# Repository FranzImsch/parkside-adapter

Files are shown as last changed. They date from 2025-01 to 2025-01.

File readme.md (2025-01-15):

## Overview

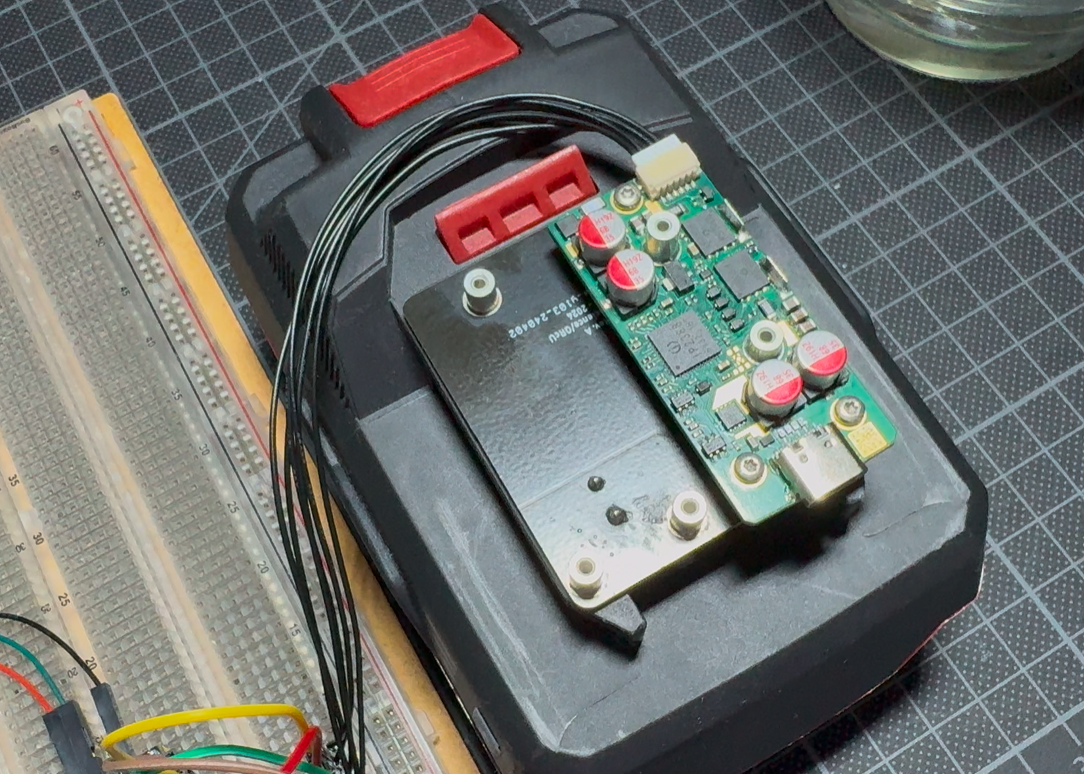
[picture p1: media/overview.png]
Overview image of test setup


Lidl sells batteries for their Parkside-branded power tools. These are 5S lithium-ion batteries that are well-constructed and cost approximately €20 for the 4 Ah version. While the cells are not from premium brands, they appear to be of relatively high quality. For instance, the 4 Ah battery I purchased contains Sunpower INR19/66 cells. Detailed information about these cells can be found here:  
[Parkside INR18650E 2000mAh (Blue) Review](https://lygte-info.dk/review/batteries2012/Parkside%20INR18650E%202000mAh%20(Blue)%20UK.html)  
[Sunpower High-Rate Lithium-Ion Battery Specifications](https://www.sunpowernewenergy.com/product/18650-high-rate-lithium-ion-battery-20p/)

Currently, Lidl offers a USB charger add-on for these batteries, but it has significant limitations. Its output power is restricted to 15 W, and it does not support charging the battery via USB.  
[Product page](https://www.lidl.de/p/parkside-20-v-akku-ladeadapter-pwca-20-li-a1/p100363956)

The adaptor described here comprises a 3D-printed enclosure and a PCB with soldered contacts that connect to the battery terminals. The interface PCB includes two mounting locations for power modules.

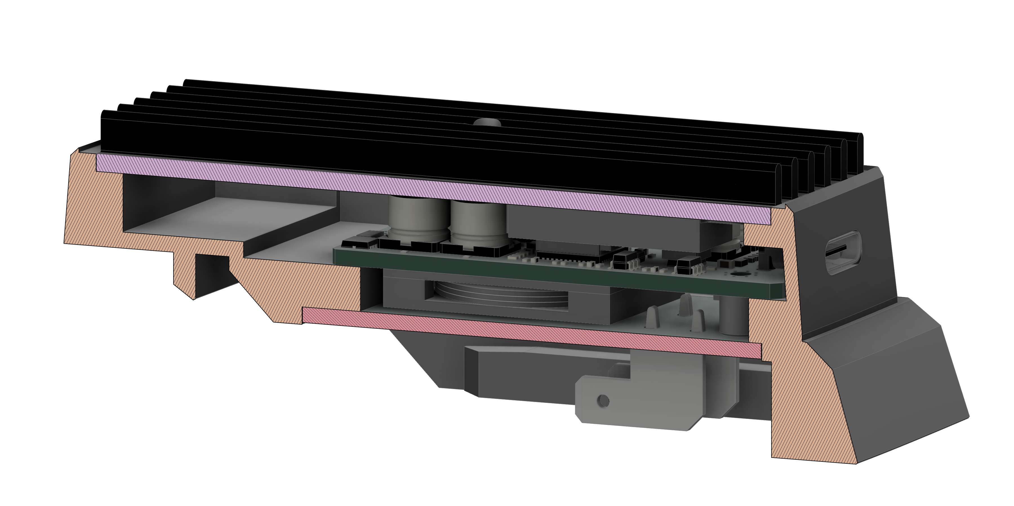
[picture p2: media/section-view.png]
Screenshot of cross section view of CAD model

The screenshot shows a cross section view of the assembly.

The bi-directional 100 W USB-C module, based on the IP2368 chip, is used in the current implementation.

Future developments are planned, including a 240 W power module and a PCB with a microcontroller and control logic.

## IP2368

The IP2368 chip is available in several firmware versions. I chose the IP2368_I2C_NACT variant, which supports I2C communication and can function as a USB-C source immediately upon connection to a battery, without requiring an initial connection to a charger. Sourcing this chip outside China is challenging; I obtained mine via [LCSC](https://www.lcsc.com/product-detail/Power-Management-Specialized_INJOINIC-IP2368_I2C_COUT_C5372184.html). Note that a quotation request is necessary, as this chip is typically not in stock.

## Tasks

- [ ] Create and expand documentation (better photos)
- [ ] Replace the overview photo  
- [ ] Design a PCB for the microcontroller  
- [ ] Test the 100 W power module

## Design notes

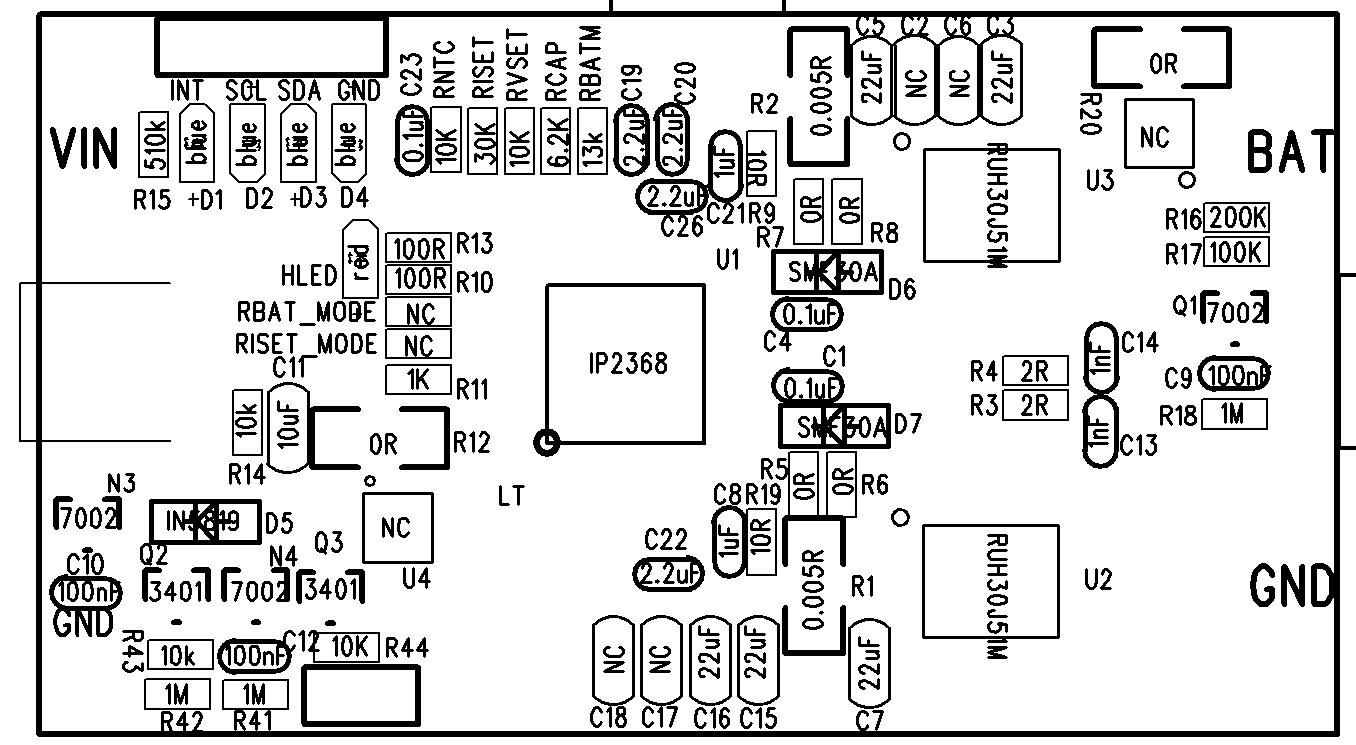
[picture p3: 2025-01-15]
IP2368-datasheets/IP2368_DEMO_V1.4.5/正面贴片图.png

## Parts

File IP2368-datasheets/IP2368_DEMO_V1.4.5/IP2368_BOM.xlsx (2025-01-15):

 | IP2368
物料名称 | 物料型号 | 位号 | 用量 | 备注
贴片电容 | 0805 10uF 25V 10% X5R | C11 | 1
贴片电容 | 0805 22uF 25V 10% X5R | C3, C5, C7, C15, C16 | 5
贴片电容 | 0603 1uF 50V 10% X5R | C8, C21 | 2
贴片电容 | 0603 100nF 50V 10% X5R | C1, C4, C9, C10, C12, C23 | 6
贴片电容 | 0603 1nF 50V 10% X5R | C13, C14 | 2
贴片电容 | 0603 2.2uF 25V 10% X5R | C19, C20, C22, C24, C25, C26 | 6
二极管 | 肖特基二极管,IN5819/S4,SOD-123 | D5 | 1
MOS管 | NMOS,2N7002,SOT23-3 | N3, N4, Q1 | 3
MOS管 | PMOS,FH3401,SOT23-3 | Q2, Q3 | 2
贴片电阻 | 0603 0R 1/10W ＋/-1% | R5, R6, R7, R8 | 4
贴片电阻 | 0603 2R 1/10W ＋/-1% | R3, R4 | 2
贴片电阻 | 0603 10R 1/10W ＋/-1% | R9, R19 | 2
贴片电阻 | 0603 100R 1/10W ＋/-1% | R10, R13 | 2
贴片电阻 | 0603 1K 1/10W ＋/-1% | R11 | 1
贴片电阻 | 0603 6.2K 1/10W ＋/-1% | RCAP | 1
贴片电阻 | 0603 10K 1/10W ＋/-1% | R14, R43, R44, RNTC, RVSET | 5
贴片电阻 | 0603 13K 1/10W ＋/-1% | RBATM | 1
贴片电阻 | 0603 30K 1/10W ＋/-1% | RISET | 1
贴片电阻 | 0603 100K 1/10W ＋/-1% | R17 | 1
贴片电阻 | 0603 200K 1/10W ＋/-1% | R16 | 1
贴片电阻 | 0603 510K 1/10W ＋/-1% | R15 | 1
贴片电阻 | 0603 1M 1/10W ＋/-1% | R18, R41, R42 | 3
贴片电阻 | 1206 0R 1W ＋/-1% | R12, R20 | 2
贴片LED | 0603 蓝色 | D1, D2, D3, D4 | 4
贴片LED | 0603 红色 | HLED | 1
IC | HT7550-2 SOT-89 | U6 | 1
TYPE-C座 | TYPE-C贴板16P,不锈钢,磷铜足1迈,高温黑胶 | USB1 | 1
插件固态电容 | 插件固态电容,100uF/35V,6.3x8 | CP1, CP2 | 2
磁环电感 | 卧式电感,10uH，T050125，直径16mm | L1 | 1
TVS管 | SMF30A,SOD-123 | D6, D7 | 2
合金电阻 | 1206 0.005R 1W ＋/-1% | R1, R2 | 2
IC | RUH30J51M PDFN5060 | U2, U3 | 2
IC | IP2368_NF | U1 | 1

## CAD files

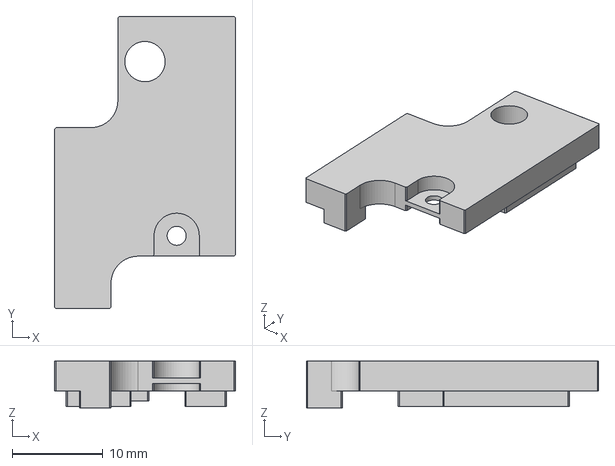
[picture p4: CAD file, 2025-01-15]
100W-Bick-KiCad/Parkside-Heatsink-Adaptor_v2.step
20.0 x 32.3 x 5.19 mm

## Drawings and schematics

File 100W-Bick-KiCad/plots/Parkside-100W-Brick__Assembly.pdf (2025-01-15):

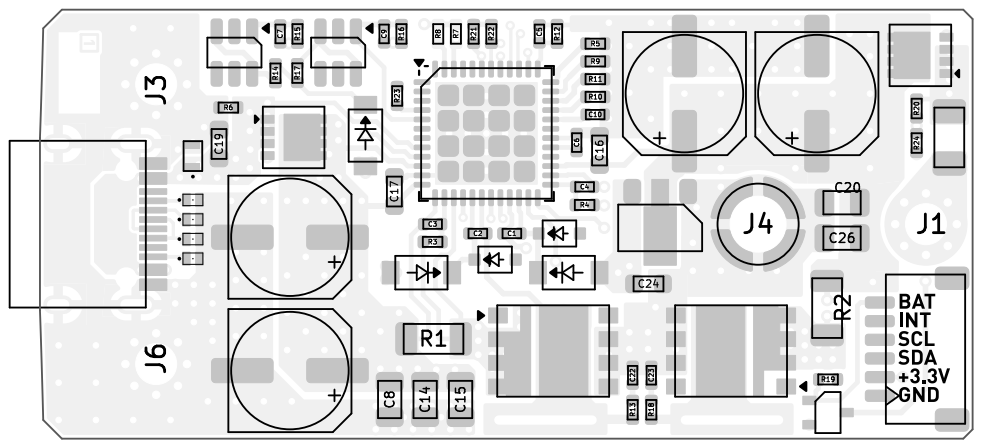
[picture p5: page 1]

Id: 1/1 Title: File: Parkside-100W-Brick.kicad_pcb Sheet: C¹⁶ R1

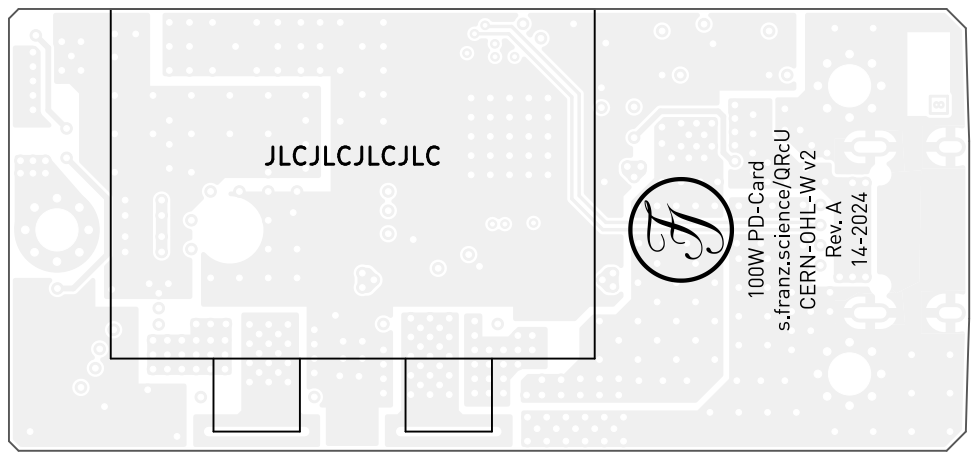
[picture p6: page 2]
D Date: KiCad; E.D.A. 8.0.0 Size: A4; Rev:

8 100WPD-Card s.franz.science/QRcU CERN-OHL-Wv2 Rev.A 14-2024 JLCJLCJLCJLC

Id: 1/1 Title: File: Parkside-100W-Brick.kicad_pcb Sheet:

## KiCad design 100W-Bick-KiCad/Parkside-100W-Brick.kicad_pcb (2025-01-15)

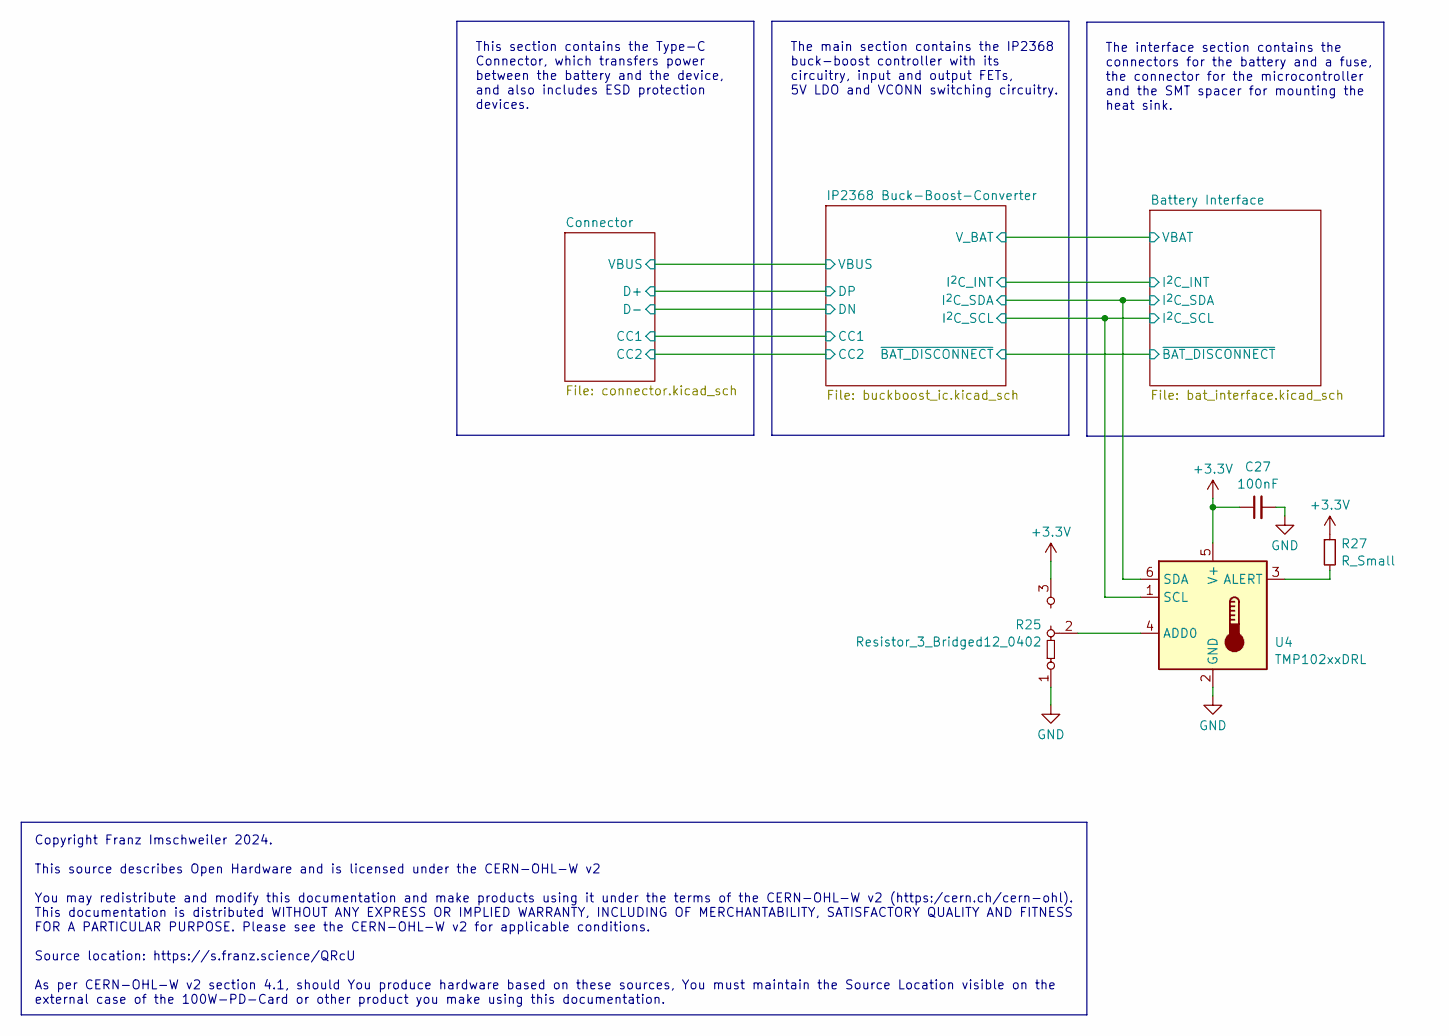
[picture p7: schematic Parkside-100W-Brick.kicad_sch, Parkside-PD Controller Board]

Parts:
C27: 100nF; C_0402_1005Metric_NoSilk
R25: Resistor_3_Bridged12_0402; R_0402_JUMPER3_NoSilk
R27: R_Small; R_0402_1005Metric_NoSilk
U4: TMP102xxDRL; SOT-563_NoSilk

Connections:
+3.3V: C27.1, R25.3 (B), R27.1, U4.5 (V+); also elsewhere on the board
/Battery Interface/I^{2}C_SCL: U4.1 (SCL); also elsewhere on the board
/Battery Interface/I^{2}C_SDA: U4.6 (SDA); also elsewhere on the board
GND: C27.2, R25.1 (A), U4.2 (GND); also elsewhere on the board
unnamed: R25.2 (C), U4.4 (ADD0)
unnamed: R27.2, U4.3 (ALERT)

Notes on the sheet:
The interface section contains the connectors for the battery and a fuse, the connector for the microcontroller and the SMT spacer for mounting the heat sink.
Copyright Franz Imschweiler 2024. This source describes Open Hardware and is licensed under the CERN-OHL-W v2 You may redistribute and modify this documentation and make products using it under the terms of the CERN-OHL-W v2 (https:/cern.ch/cern-ohl). This documentation is distributed WITHOUT ANY E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
This section contains the Type-C Connector, which transfers power between the battery and the device, and also includes ESD protection devices.
The main section contains the IP2368 buck-boost controller with its circuitry, input and output FETs, 5V LDO and VCONN switching circuitry.

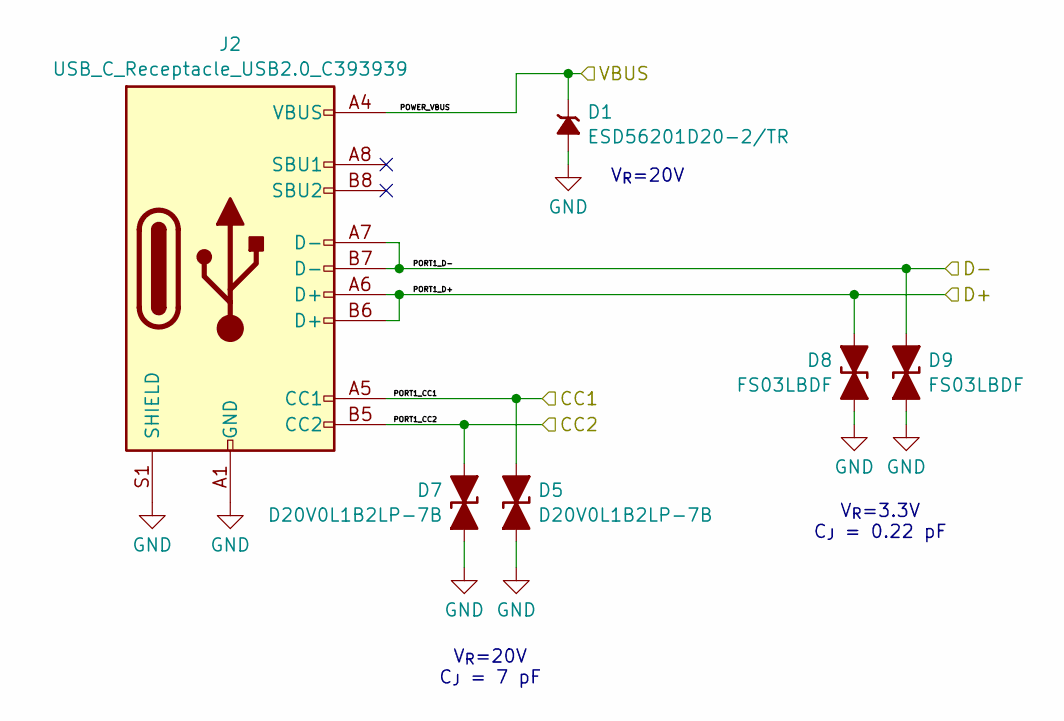
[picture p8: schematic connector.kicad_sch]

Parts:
D1: ESD56201D20-2/TR; ST_QFN1610_1_NoSilk
D5, D7: D20V0L1B2LP-7B; X1-DFN1006-2_P6X1_DIO
D8, D9: FS03LBDF; X1-DFN1006-2_P6X1_DIO
J2: USB_C_Receptacle_USB2.0_C393939; USB_C_Receptacle_C313131_TYPE-C-31-M-12

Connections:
/Connector/PORT1_CC1: D5.1 (A1), J2.A5 (CC1); also elsewhere on the board
/Connector/PORT1_CC2: D7.1 (A1), J2.B5 (CC2); also elsewhere on the board
/Connector/PORT1_D+: D8.1 (A1), J2.A6 (D+), J2.B6 (D+); also elsewhere on the board
/Connector/PORT1_D-: D9.1 (A1), J2.A7 (D-), J2.B7 (D-); also elsewhere on the board
/Connector/POWER_VBUS: D1.1 (K), J2.A4 (VBUS), J2.A9 (VBUS), J2.B4 (VBUS), J2.B9 (VBUS); also elsewhere on the board
GND: D1.2 (A), D5.2 (A2), D7.2 (A2), D8.2 (A2), D9.2 (A2), J2.A1 (GND), J2.A12 (GND), J2.B1 (GND), J2.B12 (GND), J2.S1 (SHIELD); also elsewhere on the board

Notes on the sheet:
V_{R}=20V C_{J} = 7 pF
V_{R}=20V
V_{R}=3.3V C_{J} = 0.22 pF

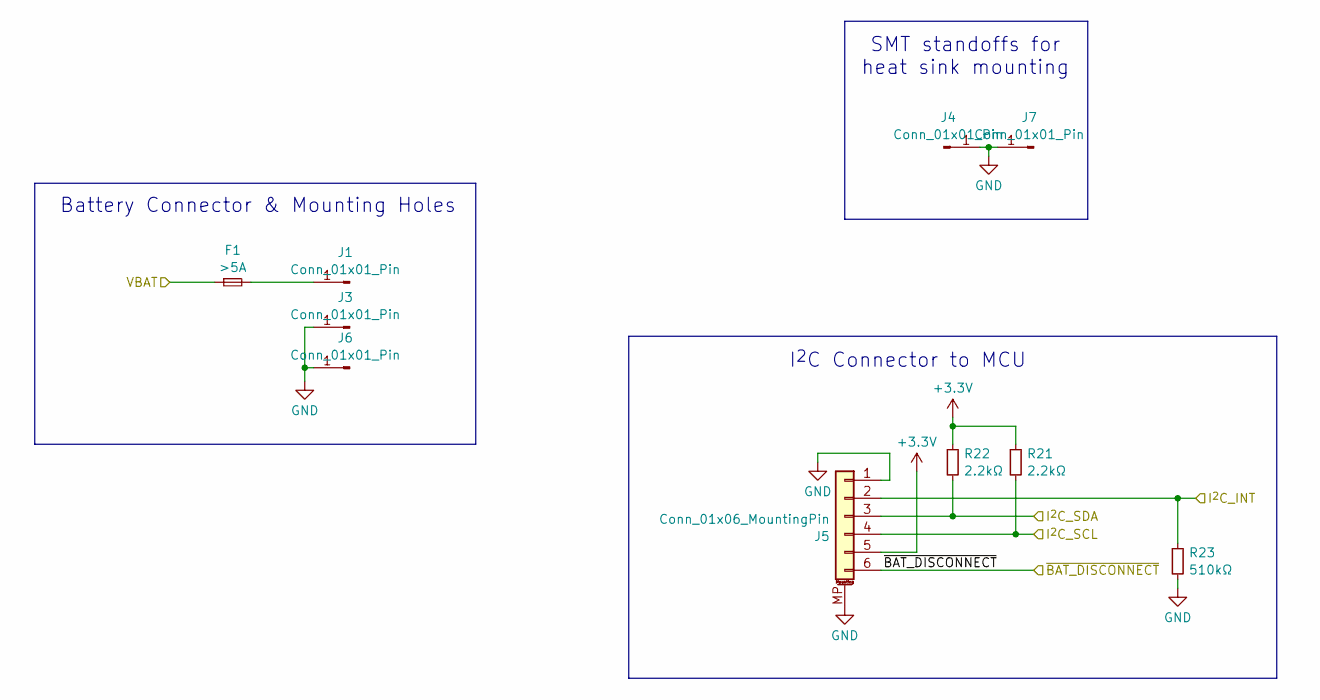
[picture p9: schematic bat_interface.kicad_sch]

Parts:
F1: >5A; Fuse_1206_3216Metric_NoSilk
J1, J3, J6: Conn_01x01_Pin; MountingHole_2.2mm_M2_Pad_Via_NoSilk
J4, J7: Conn_01x01_Pin; Mounting_Wuerth_WA-SMSI-M2_H6mm_9774060243
J5: Conn_01x06_MountingPin; JST_SH_SM06B-SRSS-TB_1x06-1MP_P1.00mm_Horizontal_NoSilk
R21, R22: 2.2kΩ; R_0402_1005Metric_NoSilk
R23: 510kΩ; R_0402_1005Metric_NoSilk

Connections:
+3.3V: J5.5, R21.1, R22.1; also elsewhere on the board
/Battery Interface/I^{2}C_INT: J5.2, R23.1; also elsewhere on the board
/Battery Interface/I^{2}C_SCL: J5.4, R21.2; also elsewhere on the board
/Battery Interface/I^{2}C_SDA: J5.3, R22.2; also elsewhere on the board
/Battery Interface/VBAT: F1.1; also elsewhere on the board
/Battery Interface/~BAT_DISCONNECT: J5.6; also elsewhere on the board
GND: J3.1, J4.1, J5.1, J5.MP (MountPin), J6.1, J7.1, R23.2; also elsewhere on the board
unnamed: F1.2, J1.1

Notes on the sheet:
Battery Connector & Mounting Holes
SMT standoffs for heat sink mounting
I^{2}C Connector to MCU

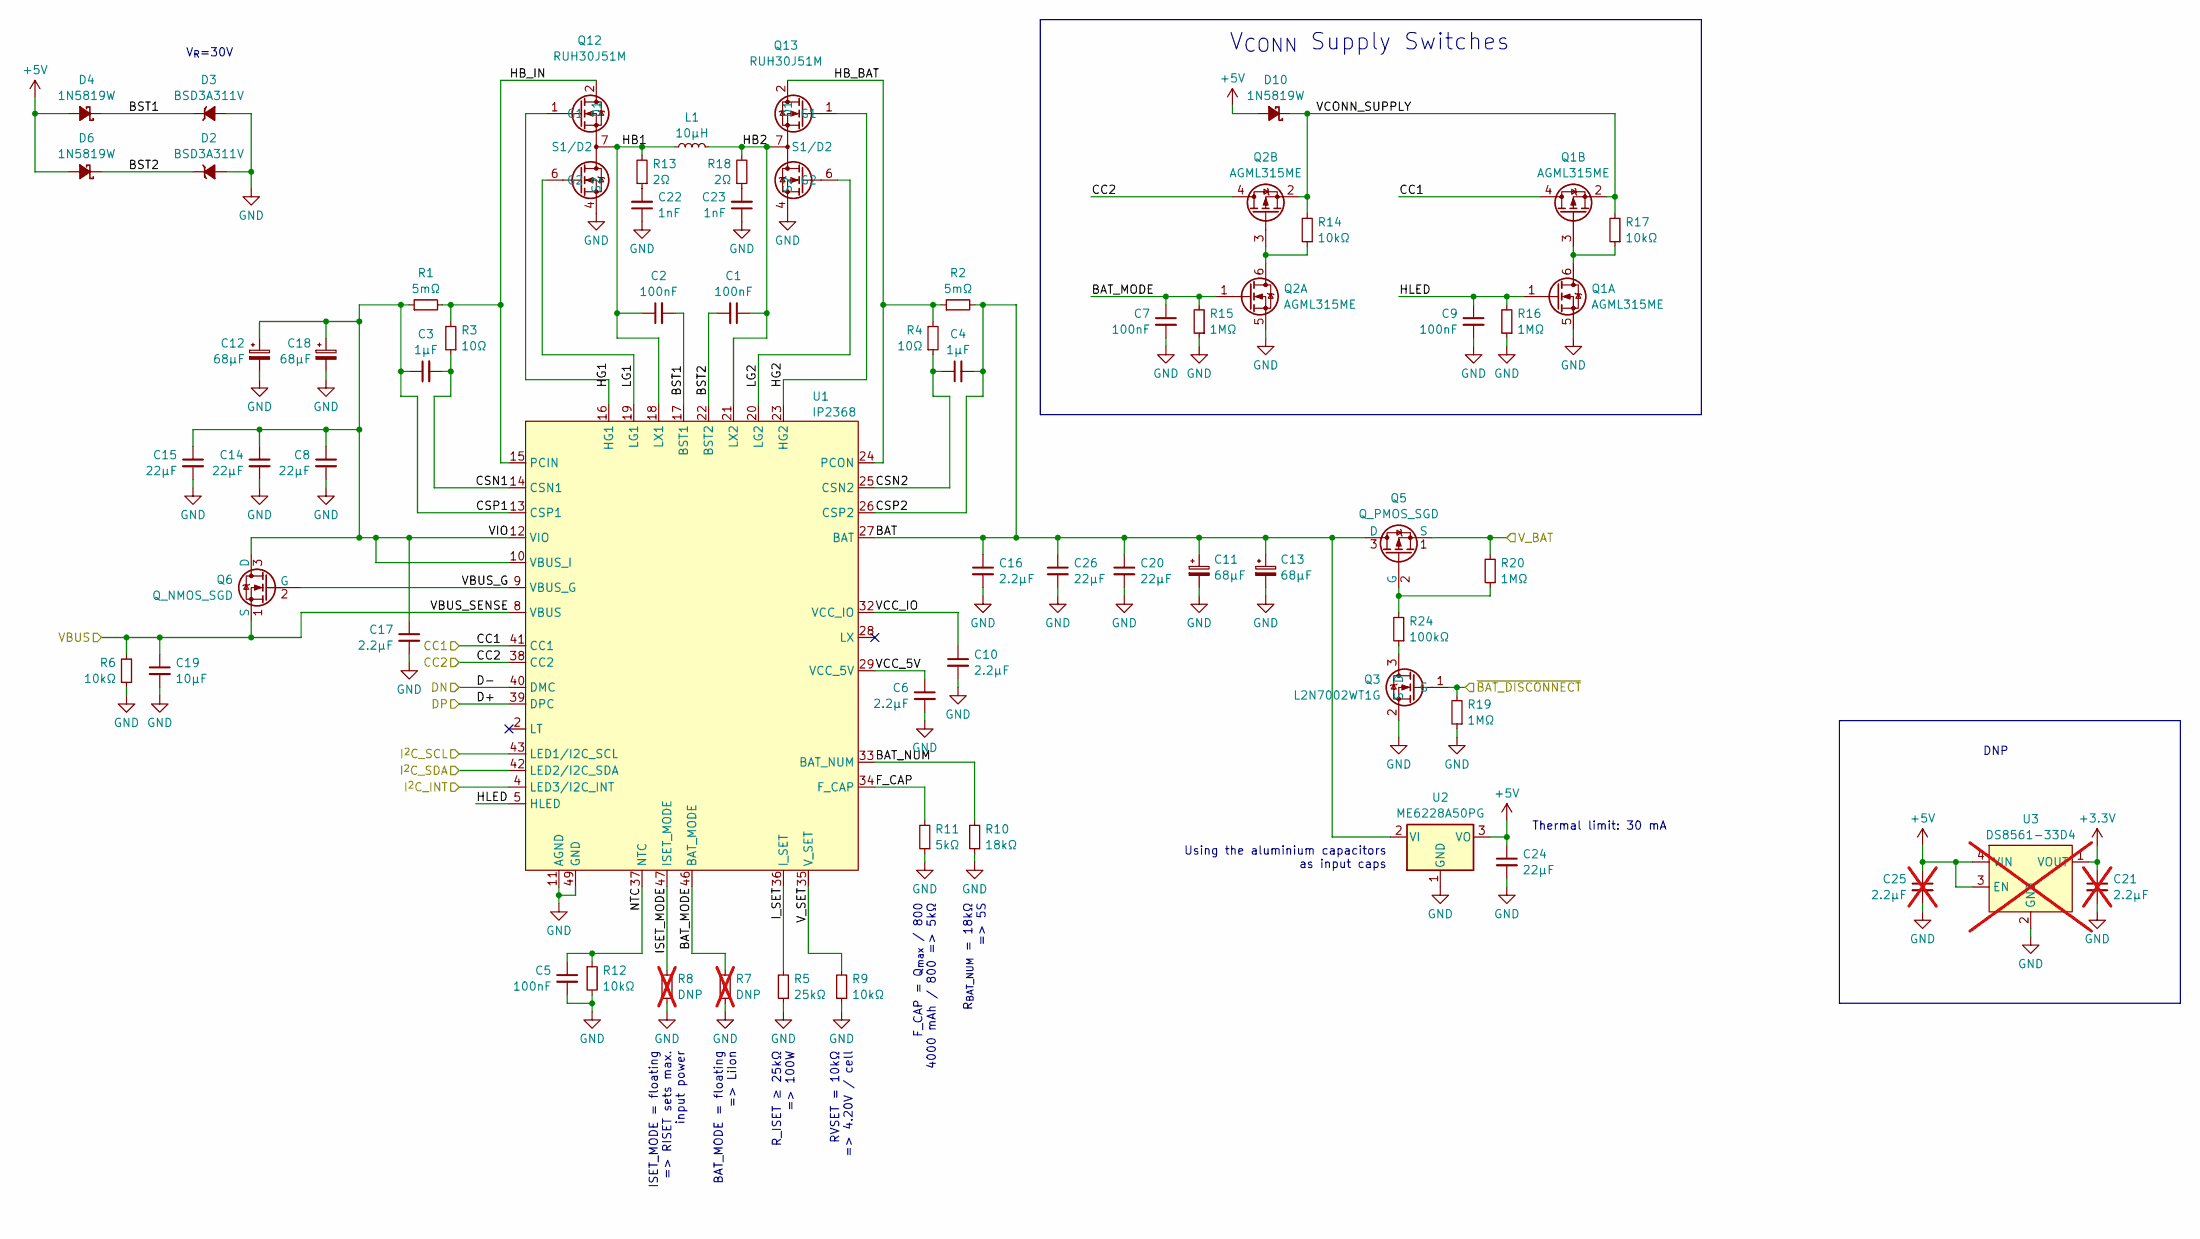
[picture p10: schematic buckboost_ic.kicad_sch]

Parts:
C1, C2, C5, C7, C9: 100nF; C_0402_1005Metric_NoSilk
C3, C4: 1µF; C_0402_1005Metric_NoSilk
C6, C10: 2.2µF; C_0402_1005Metric_NoSilk
C8, C14, C15, C20, C26: 22µF; C_0805_2012Metric_NoSilk
C11, C12, C13, C18: 68µF; CP_Elec_6.3x6.0
C16, C17: 2.2µF; C_0603_1608Metric_NoSilk
C19: 10µF; C_0603_1608Metric_NoSilk
C21, C25: 2.2µF; C_0402_1005Metric_NoSilk_DNP; not fitted
C22, C23: 1nF; C_0402_1005Metric_NoSilk
C24: 22µF; C_0603_1608Metric_NoSilk
D2, D3: BSD3A311V; D_SOD-323_SmallSilk
D4, D6, D10: 1N5819W; D_SOD-323_SmallSilk
L1: 10µH; 7443762504100
Q1, Q2: AGML315ME; SOT-23-6_NoSilk
Q3: L2N7002WT1G; SOT-323_SC-70_NoSilk
Q5: Q_PMOS_SGD; WDFN8_NoSilk
Q6: Q_NMOS_SGD; WDFN8_NoSilk
Q12, Q13: RUH30J51M; DFN-8_L6.0-W5.0-P1.27_AON6938
R1, R2: 5mΩ; R_1206_3216Metric_NoSilk
R3, R4: 10Ω; R_0402_1005Metric_NoSilk
R5: 25kΩ; R_0402_1005Metric_NoSilk
R6, R9, R12, R14, R17: 10kΩ; R_0402_1005Metric_NoSilk
R7, R8: DNP; R_0402_1005Metric_NoSilk_DNP; not fitted
R10: 18kΩ; R_0402_1005Metric_NoSilk
R11: 5kΩ; R_0402_1005Metric_NoSilk
R13, R18: 2Ω; R_0402_1005Metric_NoSilk
R15, R16, R19, R20: 1MΩ; R_0402_1005Metric_NoSilk
R24: 100kΩ; R_0402_1005Metric_NoSilk
U1: IP2368; QFN-48-1EP_7x7mm_P0.5mm_EP5.45x5.45mm_NoSilk
U2: ME6228A50PG; SOT-89-3_NoSilk
U3: DS8561-33D4; UDFN-4-1EP_1x1mm_P0.65mm_EP0.48x0.48mm_NoSilk_DNP; not fitted

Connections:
+3.3V: C21.1, U3.1 (VOUT); also elsewhere on the board
+5V: C24.1, C25.1, D4.2 (A), D6.2 (A), D10.2 (A), U2.3 (VO), U3.3 (EN), U3.4 (VIN)
/Battery Interface/I^{2}C_INT: U1.4 (LED3/I2C_INT); also elsewhere on the board
/Battery Interface/I^{2}C_SCL: U1.43 (LED1/I2C_SCL); also elsewhere on the board
/Battery Interface/I^{2}C_SDA: U1.42 (LED2/I2C_SDA); also elsewhere on the board
/Battery Interface/VBAT: Q5.1 (S), R20.2; also elsewhere on the board
/Battery Interface/~BAT_DISCONNECT: Q3.1 (G), R19.2; also elsewhere on the board
/Connector/PORT1_CC1: Q1.4 (DP), U1.41 (CC1); also elsewhere on the board
/Connector/PORT1_CC2: Q2.4 (DP), U1.38 (CC2); also elsewhere on the board
/Connector/PORT1_D+: U1.39 (DPC); also elsewhere on the board
/Connector/PORT1_D-: U1.40 (DMC); also elsewhere on the board
/Connector/POWER_VBUS: C19.1, Q6.1 (S), R6.2, U1.8 (VBUS); also elsewhere on the board
/IP2368 Buck-Boost-Converter/BAT: C4.2, C11.1, C13.1, C16.1, C20.1, C26.1, Q5.3 (D), R2.2, U1.26 (CSP2), U1.27 (BAT), U2.2 (VI)
/IP2368 Buck-Boost-Converter/BAT_MODE: C7.1, Q2.1 (GN), R7.2, R15.2, U1.46 (BAT_MODE)
/IP2368 Buck-Boost-Converter/BAT_NUM: R10.2, U1.33 (BAT_NUM)
/IP2368 Buck-Boost-Converter/BST1: C2.2, D3.1 (K), D4.1 (K), U1.17 (BST1)
/IP2368 Buck-Boost-Converter/BST2: C1.2, D2.1 (K), D6.1 (K), U1.22 (BST2)
/IP2368 Buck-Boost-Converter/CSN1: C3.2, R3.1, U1.14 (CSN1)
/IP2368 Buck-Boost-Converter/CSN2: C4.1, R4.1, U1.25 (CSN2)
/IP2368 Buck-Boost-Converter/CSP1: C3.1, C8.1, C12.1, C14.1, C15.1, C17.1, C18.1, Q6.3 (D), R1.1, U1.10 (VBUS_I), U1.12 (VIO), U1.13 (CSP1)
/IP2368 Buck-Boost-Converter/F_CAP: R11.2, U1.34 (F_CAP)
/IP2368 Buck-Boost-Converter/HB1: C2.1, L1.2, Q12.7 (S1/D2), R13.2, U1.18 (LX1)
/IP2368 Buck-Boost-Converter/HB2: C1.1, L1.1, Q13.7 (S1/D2), R18.2, U1.21 (LX2)
/IP2368 Buck-Boost-Converter/HB_BAT: Q13.2 (D1), R2.1, R4.2, U1.24 (PCON)
/IP2368 Buck-Boost-Converter/HB_IN: Q12.2 (D1), R1.2, R3.2, U1.15 (PCIN)
/IP2368 Buck-Boost-Converter/HG1: Q12.1 (G1), U1.16 (HG1)
/IP2368 Buck-Boost-Converter/HG2: Q13.1 (G1), U1.23 (HG2)
/IP2368 Buck-Boost-Converter/HLED: C9.1, Q1.1 (GN), R16.2, U1.5 (HLED)
/IP2368 Buck-Boost-Converter/ISET_MODE: R8.2, U1.47 (ISET_MODE)
/IP2368 Buck-Boost-Converter/I_SET: R5.2, U1.36 (I_SET)
/IP2368 Buck-Boost-Converter/LG1: Q12.6 (G2), U1.19 (LG1)
/IP2368 Buck-Boost-Converter/LG2: Q13.6 (G2), U1.20 (LG2)
/IP2368 Buck-Boost-Converter/NTC: C5.1, R12.1, U1.37 (NTC)
/IP2368 Buck-Boost-Converter/VBUS_G: Q6.2 (G), U1.9 (VBUS_G)
/IP2368 Buck-Boost-Converter/VCC_5V: C6.1, U1.29 (VCC_5V)
/IP2368 Buck-Boost-Converter/VCC_IO: C10.1, U1.32 (VCC_IO)
/IP2368 Buck-Boost-Converter/VCONN_SUPPLY: D10.1 (K), Q1.2 (SP), Q2.2 (SP), R14.2, R17.2
/IP2368 Buck-Boost-Converter/V_SET: R9.2, U1.35 (V_SET)
GND: C5.2, C6.2, C7.2, C8.2, C9.2, C10.2, C11.2, C12.2, C13.2, C14.2, C15.2, C16.2, C17.2, C18.2, C19.2, C20.2, C21.2, C22.1, C23.1, C24.2, C25.2, C26.2, D2.2 (A), D3.2 (A), Q1.5 (SN), Q2.5 (SN), Q3.2 (S), Q12.3 (S2), Q12.4 (S2), Q12.5 (S2), Q13.3 (S2), Q13.4 (S2), Q13.5 (S2), R5.1, R6.1, R7.1, R8.1, R9.1, R10.1, R11.1, R12.2, R15.1, R16.1, R19.1, U1.11 (AGND), U1.30 (AGND), U1.49 (GND), U2.1 (GND), U3.2 (GND), U3.5 (SGND); also elsewhere on the board
unnamed: C22.2, R13.1
unnamed: C23.2, R18.1
unnamed: Q1.3 (GP), Q1.6 (DN), R17.1
unnamed: Q2.3 (GP), Q2.6 (DN), R14.1
unnamed: Q3.3 (D), R24.1
unnamed: Q5.2 (G), R20.1, R24.2

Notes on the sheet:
F_CAP = Q_{max} / 800 4000 mAh / 800 => 5kΩ
BAT_MODE = floating => LiIon
RVSET = 10kΩ => 4.20V / cell
Thermal limit: 30 mA
Using the aluminium capacitors as input caps
ISET_MODE = floating => RISET sets max. input power
DNP
R_ISET ≥ 25kΩ => 100W
R_{BAT_NUM} = 18kΩ => 5S
V_{CONN} Supply Switches
V_{R}=30V

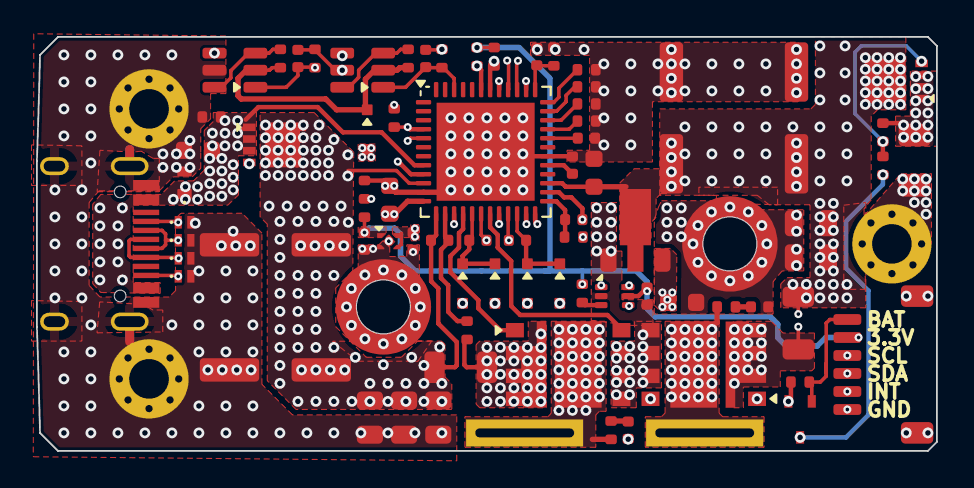
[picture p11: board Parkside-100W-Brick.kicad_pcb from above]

Board: 8 copper layers, 50.0 x 23.0 mm, 81 parts (1 on the bottom side), 47 nets.

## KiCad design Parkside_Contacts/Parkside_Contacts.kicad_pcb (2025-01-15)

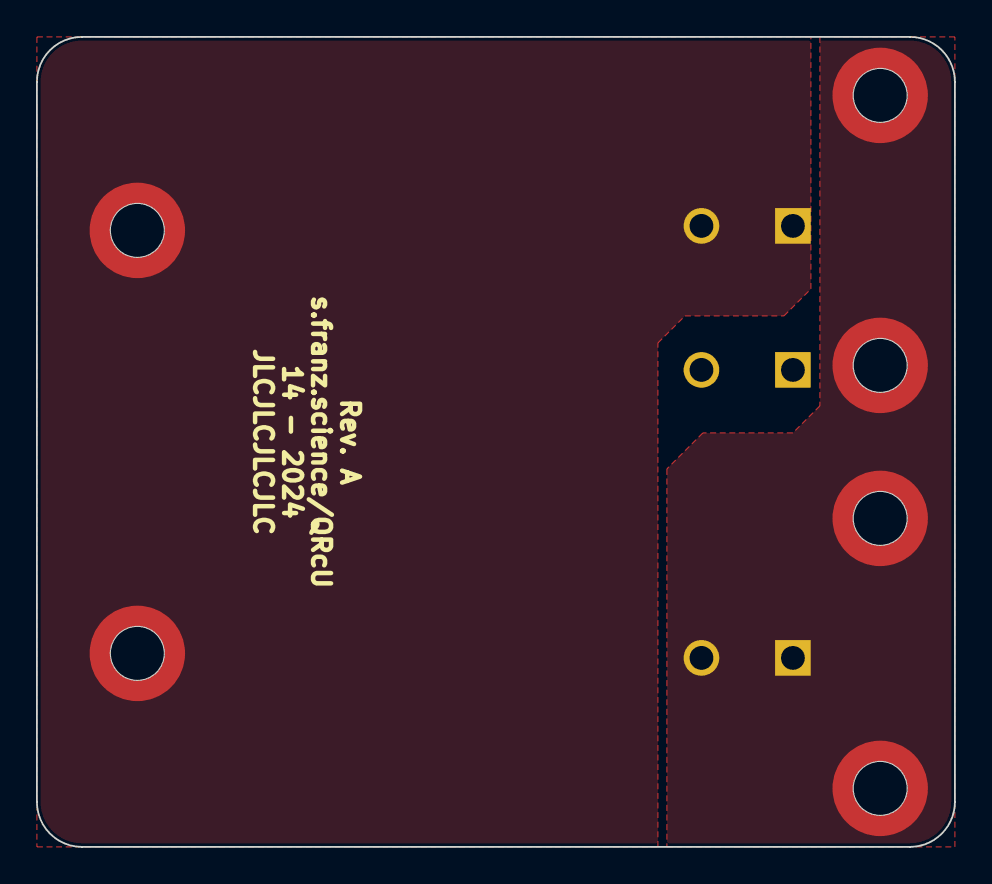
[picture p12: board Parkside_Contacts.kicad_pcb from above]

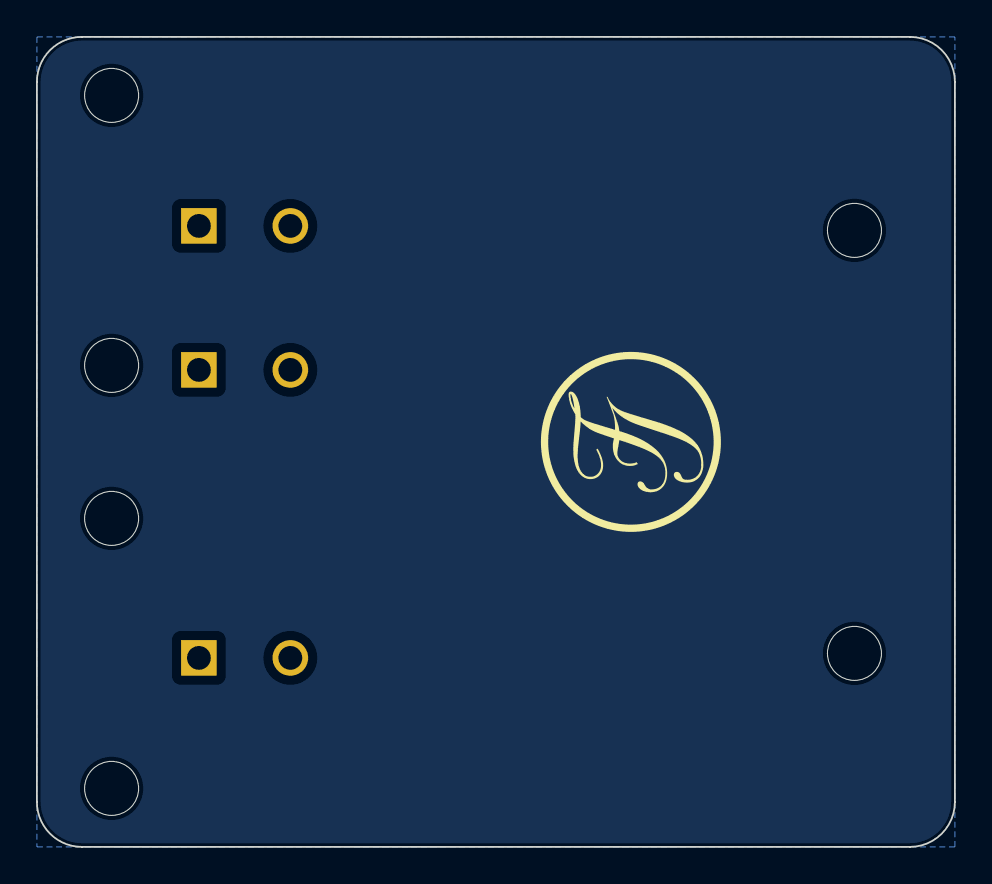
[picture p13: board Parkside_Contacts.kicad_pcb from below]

Board: 2 copper layers, 51.0 x 45.0 mm, 9 parts (3 on the bottom side), 2 nets, no tracks yet.

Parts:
J1, J2, J3: Conn_01x01_Pin; Keystone_4907
J5, J6, J7, J8, J9, J10: Conn_01x01; Mounting_Wuerth_WA-SMSI-M2_H6mm_9774060243

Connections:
GND: J3.1, J6.1, J8.1, J9.1, J10.1
unnamed: J1.1, J5.1, J7.1

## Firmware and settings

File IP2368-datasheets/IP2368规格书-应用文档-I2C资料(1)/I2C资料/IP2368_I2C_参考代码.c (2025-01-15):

IIC_type IIC = {0};
volatile uint32_t Temp = 0;

#define SCL_1                  \
    {                          \
        MFP->GPIO_DATA |= SCL; \
        Delay_Thrid_HZ();      \
    }
#define SCL_0                   \
    {                           \
        MFP->GPIO_DATA &= ~SCL; \
        Delay_Thrid_HZ();       \
    }
#define SDA_1                  \
    {                          \
        MFP->GPIO_DATA |= SDA; \
        Delay_Thrid_HZ();      \
    }
#define SDA_0                   \
    {                           \
        MFP->GPIO_DATA &= ~SDA; \
        Delay_Thrid_HZ();       \
    }

#if 0
void Delay_Thrid_HZ()
{
    for (uint32_t i = 0; i <= 1000; i++)
    {
        Temp = i;
    }
}
void DelaySend()
{
    for (uint32_t i = 0; i <= 5000; i++)
    {
        Temp = i;
    }
}
#else

/* (CPU 14Mhz) -> (5us) ,(5us) * 3 ~= 17us -> (IIC 58.5Khz) */

/* SCL波形随意,只要是稳定的周期波形即可(这里为了方便用了占空比1:2的) */

void Delay_Thrid_HZ()
{
    /* 1/3 Hz : 5us */
    for (uint32_t i = 0; i <= 10; i++)
    {
        Temp = i;
    }
}

/* 建议大于200us */
void DelaySend()
{
    for (uint32_t i = 0; i <= 300; i++)
    {
        Temp = i;
    }
}
#endif

#if 1
/* 建议I2C频率,周期要高于10倍的 (I2C_Read_Data()等 通信PACKET中的代码) 的执行时间 */
/* -> (CPU 14Mhz) -> (IIC 57Khz) */
#else
/* 建议 分析 (I2C_Read_Data()等 通信PACKET中的代码) 的执行时间,合并时间到Delay()中 */
#endif

void inline I2C_Read_Data(uint8_t i)
{
    if (MFP->GPIO_DATA & SDA)
    {
        IIC.ReceiveData |= (BIT7 >> i);
    }
}

void IIC_SEND_START()
{
    SDA_1;
    SCL_1;

    SDA_0;
    SCL_1;

    SCL_0;
}

void IIC_SEND_DATA(uint8_t data)
{
    for (uint8_t i = 0; i < 8; i++)
    {
        if ((data << i) & BIT7)
        {
            SDA_1;
        }
        else
        {
            SDA_0;
        }

        SCL_1;
        SCL_0;
    }

    SDA_1;

    MFP->GPO_EN &= ~SDA;
    MFP->GPI_EN |= SDA;

    SCL_1;

    if (MFP->GPIO_DATA & SDA)
        IIC.Crc = FALSE;
    else
        IIC.Crc = TRUE;

    SCL_0;

    MFP->GPI_EN &= ~SDA;
    MFP->GPO_EN |= SDA;

    SDA_1;

    SCL_0;
}

void IIC_RECEIVE_DATA()
{
    IIC.ReceiveData = 0;

    MFP->GPO_EN &= ~SDA;
    MFP->GPI_EN |= SDA;

    SDA_0;

#if 1
    /* 没有去支持 I2C时钟拉伸 -> 加延时(建议大于50us) */
    for (uint32_t i = 0; i <= 100; i++)
    {
        Temp = i;
    }
#else
    /* 时钟拉伸的标准处理 */
#endif

    for (uint8_t i = 0; i < 8; i++)
    {
        SCL_1;

        I2C_Read_Data(i);

        SCL_0;

        Delay_Thrid_HZ();
    }

    MFP->GPI_EN &= ~SDA;
    MFP->GPO_EN |= SDA;

    SDA_1;

    SCL_1;

    SCL_0;

    SDA_1;
}

void IIC_SEND_STOP()
{
    SDA_0;
    SCL_0;

    SCL_1;

    SDA_1;
    SCL_1;
}

void IIC_Read(uint8_t Reg)
{
    IIC_SEND_START();
    IIC_SEND_DATA(IIC.Addr << 1);
    IIC_SEND_DATA(Reg);
    DelaySend();

    IIC_SEND_START();
    IIC_SEND_DATA(IIC.Addr << 1 | BIT0);
    IIC_RECEIVE_DATA();
    IIC_SEND_STOP();
    DelaySend();
}

void IIC_Write(uint8_t Reg, uint8_t Data)
{
    IIC_SEND_START();
    IIC_SEND_DATA(IIC.Addr << 1);
    IIC_SEND_DATA(Reg);
    IIC_SEND_DATA(Data);
    IIC_SEND_STOP();
    DelaySend();
}

void IIC_Process()
{
    /* TEST */
    while (1)
    {
        DelayMs(1000);

        IIC_Read(0x00);
        IIC_Write(TEST_REG, IIC.ReceiveData);
        IIC_Read(0x01);
        IIC_Write(TEST_REG, IIC.ReceiveData);
        IIC_Read(0x02);
        IIC_Write(TEST_REG, IIC.ReceiveData);

        IIC_Read(0x31);
        IIC_Write(TEST_REG, IIC.ReceiveData);
        IIC_Read(0x32);
        IIC_Write(TEST_REG, IIC.ReceiveData);
        IIC_Read(0x33);
        IIC_Write(TEST_REG, IIC.ReceiveData);
    }
}

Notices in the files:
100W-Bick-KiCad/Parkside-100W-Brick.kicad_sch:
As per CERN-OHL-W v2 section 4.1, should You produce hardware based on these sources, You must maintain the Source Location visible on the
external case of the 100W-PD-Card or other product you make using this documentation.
